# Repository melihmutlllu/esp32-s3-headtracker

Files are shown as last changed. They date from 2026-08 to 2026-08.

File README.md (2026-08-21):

# ESP32-S3 Wireless Head Tracker

Low-power WiFi head tracker firmware for ESP32-S3 Mini + MPU9xxx-style IMU modules, designed for OpenTrack and sim games such as Euro Truck Simulator 2 and Assetto Corsa.

The current tested sensor module behaves as a 6-axis MPU6500-compatible board. The firmware can probe/use an AK8963 magnetometer when a real MPU9250-compatible module exposes it, but gyro-only yaw will still drift slowly without a working magnetometer or another absolute yaw reference.

## Features

- ESP32-S3 Mini firmware for Arduino IDE / Arduino CLI
- MPU IMU over I2C at 400 kHz
- 125 Hz sensor sampling
- 60 Hz OpenTrack UDP output
- Startup gyro calibration from current still position
- Runtime recenter and gyro recalibration commands over serial
- Low TX power WiFi mode for lower heat
- Diagnostic sketch for MPU9250 / AK8963 magnetometer probing
- PC-side UDP listener tools for debugging

## Hardware

Custom PCB: TP4056 handles LiPo charging, an MCP1825S-SOT223 LDO regulates
3.3 V for the ESP32-S3 Mini and the IMU, and a slide switch gates the battery
line. Altium source is in [`hardware/altium/`](hardware/altium/); notes on
the tested wiring, axis mapping and power budget are in
[`docs/HARDWARE.md`](docs/HARDWARE.md).

| Component | Role |
|---|---|
| ESP32-S3 Mini | MCU, WiFi, runs the firmware |
| MPU9250 / MPU6500-compatible IMU | Motion sensing over I2C |
| TP4056 module | LiPo charge controller (USB input) |
| MCP1825S-SOT223 | 3.3 V LDO for the ESP32 + IMU rail |
| 1S LiPo battery | Power source |
| Slide switch | Power on/off |

| Schematic | 3D view | Routed layout |
|---|---|---|
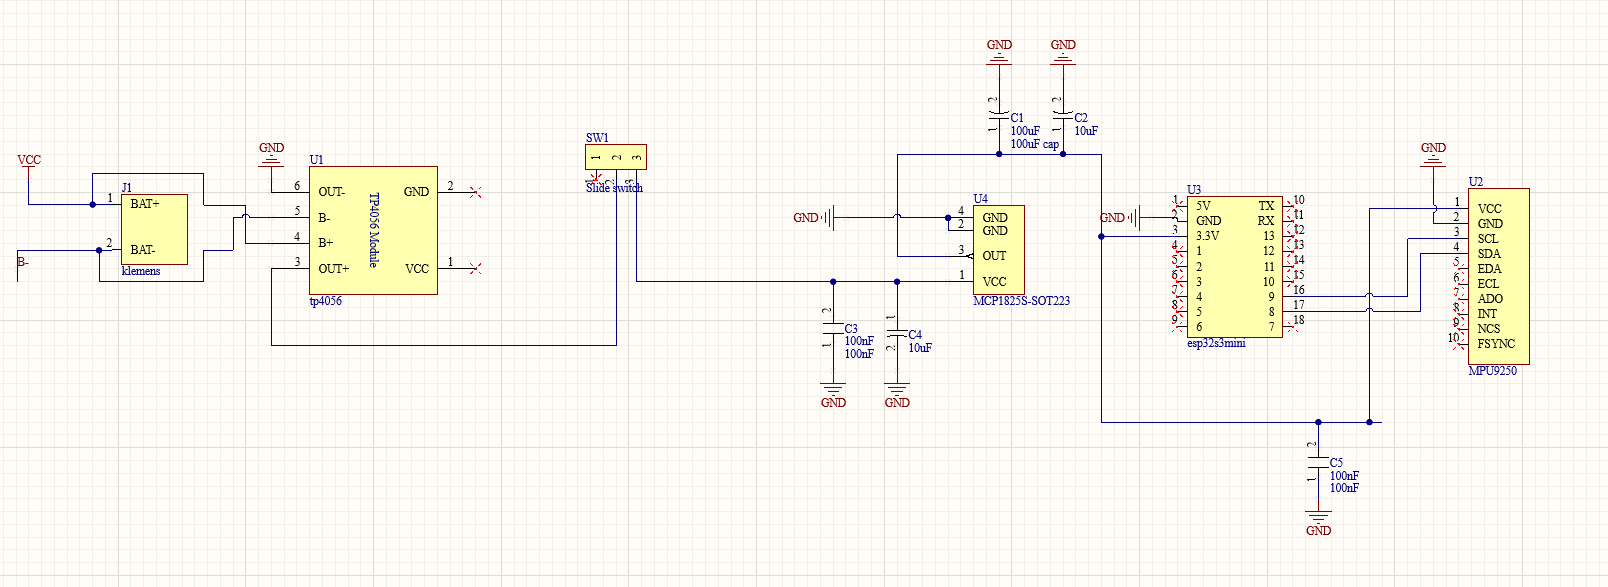
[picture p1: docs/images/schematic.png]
Schematic
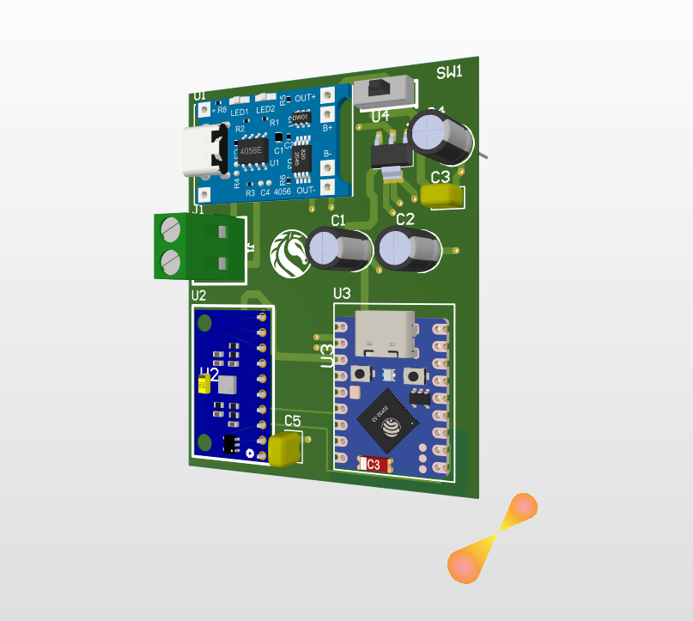
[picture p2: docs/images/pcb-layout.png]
Routed layout
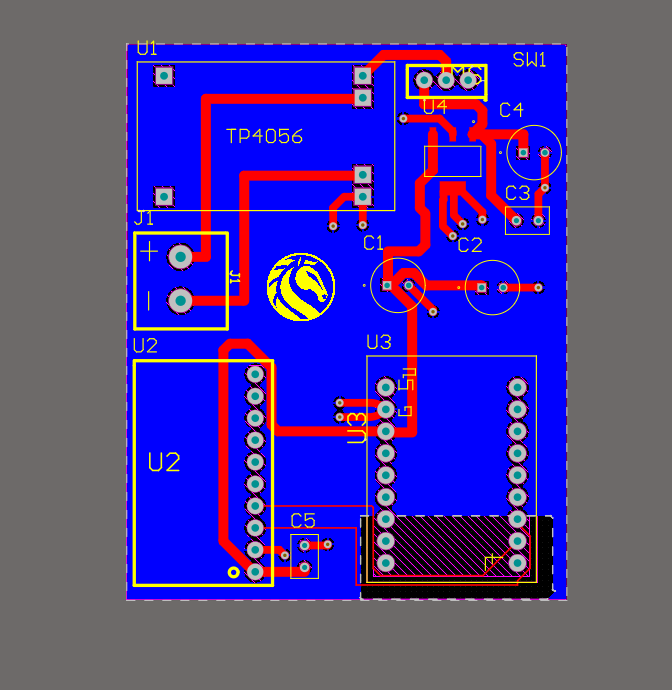
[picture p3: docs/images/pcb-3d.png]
3D view
|  |  |  |

## Repository Layout 

```text
firmware/headtracker_udp_lowpower/        Main firmware
firmware/diagnostics/mpu9250_deep_probe/ Deep MPU9250/AK8963 probe sketch
hardware/altium/                         Altium project (schematic, PCB, libraries)
tools/                                   PC-side debug tools
docs/                                    Setup, hardware and troubleshooting notes
```

## Quick Start

1. Open `firmware/headtracker_udp_lowpower/headtracker_udp_lowpower.ino` in Arduino IDE.
2. Copy `secrets.example.h` to `secrets.h` in the same folder.
3. Fill WiFi SSID, WiFi password, and the PC IPv4 address running OpenTrack.
4. Select the ESP32-S3 Mini board. The tested Arduino CLI FQBN is:

```powershell
esp32:esp32:lolin_s3_mini:CDCOnBoot=cdc
```

5. Upload the sketch.
6. Keep the tracker completely still during startup calibration.
7. In OpenTrack, use UDP input on port `4242`.

## Serial Commands

Send these from Arduino Serial Monitor:

```text
c  recenter current pose
b  recalibrate gyro bias and recenter; keep sensor still
m  toggle magnetometer yaw correction
s  scan I2C bus
h  print help
```

## OpenTrack Packet

The firmware sends one UDP packet containing six little-endian `double` values:

```text
tx, ty, tz, yaw_deg, pitch_deg, roll_deg
```

Only rotational axes are used. Roll is currently sent as `0` by default because the in-game setup was tuned with roll disabled.

## Important Notes

- Do not commit `secrets.h`; it contains WiFi credentials.
- If OpenTrack stops seeing the tracker after days/weeks, the PC IP probably changed. Update `HEADTRACKER_OPENTRACK_PC_IP` in `secrets.h`, or reserve a fixed DHCP address for the PC in the router.
- For real yaw drift correction, use a module with a working magnetometer or add an external magnetometer on the I2C bus.
- A real MPU9250/AK8963 setup should show `0x68` and `0x0C` in the I2C scan, with AK8963 `WHO_AM_I = 0x48`.

## Demo

Demo video (https://youtube.com/shorts/CIPEAHezTM8)

The tracker responding to head movement in real time, hand-held for clarity.
This clip is running on an earlier perfboard prototype rather than the PCB
shown above; the wiring is the same as the schematic.

## Status

PCB designed and firmware validated on the bench (prototype hardware); a
populated version of the board above and an enclosure are the next steps.

## License

MIT — see [LICENSE](LICENSE).

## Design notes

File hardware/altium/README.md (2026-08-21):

# Altium Files

Custom PCB source for the tracker board: TP4056 charge input, MCP1825S-SOT223
3.3 V LDO feeding the ESP32-S3 Mini and MPU9250, and a slide switch on the
battery line.

```text
headtracking_.PrjPcb   Project file
headtracking.SchDoc    Schematic
PCB1.PcbDoc             Board layout
Schlib1.SchLib          Custom schematic symbols (module footprints as blocks)
PcbLib2.PcbLib          Custom PCB footprints
```

Renders/exports of the current revision are in [`../images`](../images):
[schematic](../images/schematic.png), [3D view](../images/pcb-3d.png),
[routed layout](../images/pcb-layout.png).

Open `headtracking_.PrjPcb` in Altium Designer to edit. Commit these
source/design file types when present:

```text
*.PrjPcb
*.SchDoc
*.PcbDoc
*.SchLib
*.PcbLib
*.OutJob
*.BomDoc
```

Generated/local folders are excluded by `.gitignore` and should not be committed:

```text
History/
__Previews/
Project Outputs*/
```

Suggested release/export structure if you want to publish manufacturing files:

```text
hardware/outputs/gerber/
hardware/outputs/assembly/
hardware/outputs/bom/
hardware/outputs/pdf/
```

`hardware/outputs/` is ignored by default. For public releases, attach generated Gerber/NC drill/BOM/assembly files to a GitHub Release, or remove that ignore rule when you intentionally want them tracked.

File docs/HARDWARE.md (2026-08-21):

# Hardware Notes

## Tested Wiring

ESP32-S3 Mini to IMU:

```text
ESP32-S3 3V3  -> IMU VCC
ESP32-S3 GND  -> IMU GND
ESP32-S3 GPIO8 -> IMU SDA
ESP32-S3 GPIO9 -> IMU SCL
```

The firmware configures I2C at `400 kHz`.

## Sensor Orientation

The current firmware maps the mounted sensor frame like this:

```text
logical X = sensor Y
logical Y = sensor X
logical Z = -sensor Z
```

The output signs are currently tuned so that right yaw and up pitch increase in OpenTrack.

## Power

WiFi bursts can expose weak 3.3 V supplies. For stable behavior:

- Use a clean 3.3 V rail.
- Budget at least 500 mA for the ESP32 board.
- Add local decoupling near the ESP32/IMU.
- A practical starting point is 470 uF bulk plus 10 uF and 100 nF close to the board.

If the board heats excessively from USB, test with a stable external 3.3 V supply and keep WiFi TX power low.

## Magnetometer Reality Check

For a real MPU9250 with AK8963 magnetometer, the deep probe should find:

```text
i2c_device=0x68
i2c_device=0x0C
ak8963_ack=true
ak8963_wia=0x48
```

If only `0x68` appears after bypass, the module behaves like a 6-axis MPU6500-style board or has a disconnected/faulty magnetometer.

SDO/AD0 only changes the main MPU address between `0x68` and `0x69`; it does not make the AK8963 magnetometer appear.

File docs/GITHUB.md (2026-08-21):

# Publishing via the GitHub Website

This project is meant to be uploaded through github.com's web UI, not `git push`.
No local git setup is required.

## Before Uploading

**Do not upload `firmware/headtracker_udp_lowpower/secrets.h` if you created one.**
`.gitignore` only protects you when you use `git`; a browser upload has no such
filter, so it's on you to leave that file out manually. Only
`secrets.example.h` should go up.

## Steps

1. On GitHub, create a new repository (e.g. `esp32-s3-headtracker`). Leave
   "Add a README" / `.gitignore` / license unchecked — this project already
   has them.
2. Open the empty repo, click **Add file > Upload files**.
3. Drag the whole project folder in (GitHub preserves subfolder structure —
   `firmware/`, `hardware/`, `docs/`, `tools/` will show up as-is). If it
   only accepts loose files in your browser, upload folder by folder instead.
4. Double-check `secrets.h` isn't in the list of staged files before you commit.
5. Commit directly to `main`.

## Limits to Know

- 25 MiB per file via the web uploader, up to 100 files per upload batch.
  The largest file here is `hardware/altium/PCB1.PcbDoc` at ~3.8 MB, so
  everything fits in one pass.
- If GitHub ever flags a file as too large or the folder drag doesn't work
  in your browser, upload `hardware/altium/` separately from the rest.

## Altium Sources

Already included in `hardware/altium/`:

```text
headtracking_.PrjPcb   Project file
headtracking.SchDoc    Schematic
PCB1.PcbDoc             Board layout
Schlib1.SchLib          Custom schematic symbols
PcbLib2.PcbLib          Custom PCB footprints
```

If you regenerate these in Altium later and re-upload, skip committing its
generated/local output folders (`History/`, `__Previews/`, `Project Outputs*/`).

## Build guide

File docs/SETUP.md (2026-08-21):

# Setup

## Arduino

Tested with Arduino IDE and the ESP32 board package.

Board/FQBN:

```powershell
esp32:esp32:lolin_s3_mini:CDCOnBoot=cdc
```

Compile with Arduino CLI:

```powershell
arduino-cli compile --fqbn esp32:esp32:lolin_s3_mini:CDCOnBoot=cdc firmware/headtracker_udp_lowpower
```

Upload example:

```powershell
arduino-cli upload -p COM23 --fqbn esp32:esp32:lolin_s3_mini:CDCOnBoot=cdc firmware/headtracker_udp_lowpower
```

## Local Secrets

Create:

```text
firmware/headtracker_udp_lowpower/secrets.h
```

from:

```text
firmware/headtracker_udp_lowpower/secrets.example.h
```

Example:

```cpp
#pragma once

#define HEADTRACKER_WIFI_SSID "your-wifi-name"
#define HEADTRACKER_WIFI_PASSWORD "your-wifi-password"
#define HEADTRACKER_OPENTRACK_PC_IP 192, 168, 1, 3
```

To find the PC IP on Windows:

```powershell
Get-NetIPAddress -AddressFamily IPv4
```

Use the IPv4 address of the WiFi adapter that is on the same network as the ESP32.

## OpenTrack

- Input: UDP over network
- Port: `4242`
- Output: FreeTrack 2.0 Enhanced, or TrackIR if a game needs it
- Filter: Accela is a good starting point

OpenTrack centering does not update the ESP32's internal center. For quick use this is fine, but for a more polished build add a physical recenter button or send the serial `c` command to the ESP32.

## Startup Calibration

Keep the tracker still after power-up. The firmware waits for WiFi, lets the board settle, and then collects gyro/accel calibration samples.

If the first calibration was noisy, keep it still and send:

```text
b
```

from Serial Monitor.

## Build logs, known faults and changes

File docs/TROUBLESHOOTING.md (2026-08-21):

# Troubleshooting

## OpenTrack Does Not See Data

Check the firmware serial output:

```text
wifi_status=3
local_ip=...
udp_target=PC_IP:4242
```

Then verify:

- The PC IPv4 address in `secrets.h` matches the current Windows WiFi IP.
- OpenTrack input is set to UDP on port `4242`.
- Windows firewall allows OpenTrack or the UDP listener.
- The ESP32 and PC are on the same network.

PC IP can change with DHCP. The clean fix is a DHCP reservation in the router.

## Test UDP Without OpenTrack

Close OpenTrack first, because only one program should bind port `4242`.

Python:

```powershell
python tools/udp_pose_receiver.py
```

PowerShell:

```powershell
powershell -ExecutionPolicy Bypass -File tools/listen_udp_4242.ps1
```

## Yaw Drift

Gyro-only yaw has no absolute reference, so it will drift. The firmware reduces drift with startup calibration and slow stationary gyro bias updates, but a working magnetometer or another external reference is required for true yaw correction.

If drift gets worse as the board warms:

1. Power the tracker.
2. Keep it completely still through startup calibration.
3. Let it sit still for another 30-60 seconds.
4. Recenter in OpenTrack.

If needed, send serial command:

```text
b
```

after the board is warm and completely still.

## Magnetometer Not Found

Run:

```text
firmware/diagnostics/mpu9250_deep_probe/mpu9250_deep_probe.ino
```

Expected for a working MPU9250/AK8963:

```text
i2c_device=0x68
i2c_device=0x0C
ak8963_wia=0x48
```

If `0x0C` never appears, the magnetometer is not accessible.

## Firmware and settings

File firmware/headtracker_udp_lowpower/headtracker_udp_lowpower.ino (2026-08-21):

#include <Arduino.h>
#include <esp_system.h>
#include <esp_wifi.h>
#include <WiFi.h>
#include <WiFiUdp.h>
#include <Wire.h>

#if __has_include("secrets.h")
#include "secrets.h"
#endif

// ESP32-S3 Mini + MPU9250 head-tracker fusion test.
// Serial commands:
//   c = recenter current head pose
//   b = recalibrate gyro bias and recenter (keep still)
//   m = toggle magnetometer yaw correction
//   s = scan I2C bus
//   h = print help

static constexpr uint8_t SDA_PIN = 8;
static constexpr uint8_t SCL_PIN = 9;
static constexpr uint8_t MPU_ADDR = 0x68;

static constexpr uint32_t SERIAL_BAUD = 115200;
static constexpr uint32_t I2C_CLOCK_HZ = 400000;
static constexpr uint32_t SAMPLE_RATE_HZ = 125;
static constexpr uint32_t PRINT_RATE_HZ = 1;
static constexpr uint32_t UDP_SEND_RATE_HZ = 60;
static constexpr uint16_t CALIBRATION_SAMPLES = 750;
static constexpr uint32_t POST_WIFI_CALIBRATION_SETTLE_MS = 5000;
static constexpr uint32_t MAX_FILTER_DT_US = 10000;
static constexpr uint32_t ECO_CPU_MHZ = 80;
static constexpr bool SERIAL_PLOTTER_MODE = false;
static constexpr bool ENABLE_WIFI_UDP = true;
static constexpr bool ENABLE_AP_FALLBACK = false;
static constexpr bool SEND_ROLL_TO_OPENTRACK = false;
static constexpr bool ENABLE_OUTPUT_SMOOTHING = false;
static constexpr bool ENABLE_AUTO_GYRO_BIAS = true;
static constexpr bool WIFI_LOW_LATENCY_MODE = true;
static constexpr bool USE_UNICAST_TARGET = true;
static constexpr bool ENABLE_MAG_YAW_CORRECTION = true;
static constexpr uint32_t MPU_BASE_SAMPLE_RATE_HZ = 1000;
static constexpr uint8_t MPU_SAMPLE_RATE_DIVIDER =
  static_cast<uint8_t>((MPU_BASE_SAMPLE_RATE_HZ / SAMPLE_RATE_HZ) - 1);
static constexpr wifi_power_t WIFI_TX_POWER = WIFI_POWER_2dBm;

static_assert(MPU_BASE_SAMPLE_RATE_HZ % SAMPLE_RATE_HZ == 0,
              "SAMPLE_RATE_HZ must divide the MPU 1 kHz base rate");

#ifndef HEADTRACKER_WIFI_SSID
#define HEADTRACKER_WIFI_SSID ""
#endif

#ifndef HEADTRACKER_WIFI_PASSWORD
#define HEADTRACKER_WIFI_PASSWORD ""
#endif

#ifndef HEADTRACKER_OPENTRACK_PC_IP
#define HEADTRACKER_OPENTRACK_PC_IP 192, 168, 1, 3
#endif

#ifndef HEADTRACKER_AP_SSID
#define HEADTRACKER_AP_SSID "ESP32-HeadTracker"
#endif

#ifndef HEADTRACKER_AP_PASSWORD
#define HEADTRACKER_AP_PASSWORD "headtrack123"
#endif

// Fill secrets.h for normal WiFi station mode. Leave HEADTRACKER_WIFI_SSID
// empty to make the ESP32 create its own test access point instead.
static const char WIFI_SSID[] = HEADTRACKER_WIFI_SSID;
static const char WIFI_PASSWORD[] = HEADTRACKER_WIFI_PASSWORD;
static const char AP_SSID[] = HEADTRACKER_AP_SSID;
static const char AP_PASSWORD[] = HEADTRACKER_AP_PASSWORD;

static constexpr uint16_t OPENTRACK_UDP_PORT = 4242;
static constexpr uint32_t WIFI_CONNECT_TIMEOUT_MS = 30000;
static constexpr uint32_t WIFI_RECONNECT_INTERVAL_MS = 5000;
static constexpr uint8_t MAX_CONSECUTIVE_I2C_ERRORS = 8;
static constexpr uint16_t CALIBRATION_MIN_GOOD_SAMPLES = (CALIBRATION_SAMPLES * 9) / 10;
static constexpr uint8_t CALIBRATION_MAX_ATTEMPTS = 3;
static constexpr float CALIBRATION_ACCEL_MIN_G = 0.80f;
static constexpr float CALIBRATION_ACCEL_MAX_G = 1.20f;
static constexpr float CALIBRATION_MAX_ACCEL_STD_G = 0.05f;
static constexpr float CALIBRATION_MAX_GYRO_STD_DPS = 0.80f;
static constexpr float AUTO_BIAS_ACCEL_MIN_G = 0.90f;
static constexpr float AUTO_BIAS_ACCEL_MAX_G = 1.10f;
static constexpr float AUTO_BIAS_GYRO_XY_MAX_DPS = 0.35f;
static constexpr float AUTO_BIAS_GYRO_Z_MAX_DPS = 0.80f;
static constexpr float AUTO_BIAS_ALPHA_XY = 0.00015f;
static constexpr float AUTO_BIAS_ALPHA_Z = 0.00055f;
static constexpr uint16_t AUTO_BIAS_SETTLE_SAMPLES = static_cast<uint16_t>((SAMPLE_RATE_HZ * 3) / 2);
static constexpr float OUTPUT_SMOOTH_TAU_SLOW_S = 0.090f;
static constexpr float OUTPUT_SMOOTH_TAU_FAST_S = 0.018f;
static constexpr float OUTPUT_SMOOTH_SPEED_SLOW_DPS = 20.0f;
static constexpr float OUTPUT_SMOOTH_SPEED_FAST_DPS = 180.0f;
static constexpr float OUTPUT_MAX_RATE_DPS = 900.0f;
static constexpr float MAG_YAW_SIGN = 1.0f;
static constexpr float MAG_YAW_CORRECTION_GAIN = 0.25f;
static constexpr float MAG_YAW_MAX_CORRECTION_DPS = 2.0f;
static constexpr float MAG_YAW_FILTER_TAU_S = 0.70f;
static constexpr float MAG_FIELD_MIN_UT = 10.0f;
static constexpr float MAG_FIELD_MAX_UT = 90.0f;
static constexpr float MAG_MAX_TRUSTED_ERROR_DEG = 45.0f;
static constexpr float MAG_CORRECTION_MAX_GYRO_DPS = 160.0f;
static constexpr float MAG_BIAS_X_UT = 0.0f;
static constexpr float MAG_BIAS_Y_UT = 0.0f;
static constexpr float MAG_BIAS_Z_UT = 0.0f;
static constexpr float MAG_SCALE_X = 1.0f;
static constexpr float MAG_SCALE_Y = 1.0f;
static constexpr float MAG_SCALE_Z = 1.0f;
static IPAddress OPENTRACK_PC_IP(HEADTRACKER_OPENTRACK_PC_IP);

// MPU9250 full scale settings used below:
// accel +/-4 g => 8192 LSB/g, gyro +/-500 dps => 65.5 LSB/dps.
static constexpr float ACCEL_LSB_PER_G = 8192.0f;
static constexpr float GYRO_LSB_PER_DPS = 65.5f;
static constexpr float TEMP_LSB_PER_C = 333.87f;
static constexpr float TEMP_OFFSET_C = 21.0f;
static constexpr float DEG_TO_RAD_F = 0.01745329251994329577f;
static constexpr float RAD_TO_DEG_F = 57.295779513082320876f;

// Register map subset.
static constexpr uint8_t REG_SMPLRT_DIV = 0x19;
static constexpr uint8_t REG_CONFIG = 0x1A;
static constexpr uint8_t REG_GYRO_CONFIG = 0x1B;
static constexpr uint8_t REG_ACCEL_CONFIG = 0x1C;
static constexpr uint8_t REG_ACCEL_CONFIG2 = 0x1D;
static constexpr uint8_t REG_INT_PIN_CFG = 0x37;
static constexpr uint8_t REG_ACCEL_XOUT_H = 0x3B;
static constexpr uint8_t REG_USER_CTRL = 0x6A;
static constexpr uint8_t REG_PWR_MGMT_1 = 0x6B;
static constexpr uint8_t REG_PWR_MGMT_2 = 0x6C;
static constexpr uint8_t REG_WHO_AM_I = 0x75;

// AK8963 magnetometer inside MPU9250. It is reached through I2C bypass.
static constexpr uint8_t MAG_ADDR = 0x0C;
static constexpr uint8_t MAG_REG_WIA = 0x00;
static constexpr uint8_t MAG_REG_ST1 = 0x02;
static constexpr uint8_t MAG_REG_HXL = 0x03;
static constexpr uint8_t MAG_REG_ST2 = 0x09;
static constexpr uint8_t MAG_REG_CNTL1 = 0x0A;
static constexpr uint8_t MAG_REG_CNTL2 = 0x0B;
static constexpr uint8_t MAG_REG_ASAX = 0x10;
static constexpr uint8_t MAG_MODE_POWER_DOWN = 0x00;
static constexpr uint8_t MAG_MODE_FUSE_ROM = 0x0F;
static constexpr uint8_t MAG_MODE_CONT_100HZ_16BIT = 0x16;

// Map sensor axes into a right-handed head/game frame:
//   logical X = physical roll axis  = sensor Y
//   logical Y = physical pitch axis = sensor X
//   logical Z = physical yaw axis   = -sensor Z
// The signs can still be adjusted later if OpenTrack direction feels reversed.
enum AxisIndex : uint8_t { AXIS_X = 0, AXIS_Y = 1, AXIS_Z = 2 };
static constexpr AxisIndex MAP_OUT_X = AXIS_Y;
static constexpr AxisIndex MAP_OUT_Y = AXIS_X;
static constexpr AxisIndex MAP_OUT_Z = AXIS_Z;
static constexpr float SIGN_OUT_X = 1.0f;
static constexpr float SIGN_OUT_Y = 1.0f;
static constexpr float SIGN_OUT_Z = -1.0f;

static constexpr float OUTPUT_YAW_SIGN = -1.0f;
static constexpr float OUTPUT_PITCH_SIGN = -1.0f;
static constexpr float OUTPUT_ROLL_SIGN = 1.0f;

// Mahony 6DOF gain. Higher follows accelerometer faster; lower is smoother.
static constexpr float MAHONY_TWO_KP = 2.0f * 1.0f;
static constexpr float MAHONY_TWO_KI = 2.0f * 0.02f;

static_assert(sizeof(double) == 8, "OpenTrack UDP packet needs 64-bit doubles");

struct RawImu {
  int16_t ax;
  int16_t ay;
  int16_t az;
  int16_t temp;
  int16_t gx;
  int16_t gy;
  int16_t gz;
};

struct Vec3 {
  float x;
  float y;
  float z;
};

struct Quat {
  float w;
  float x;
  float y;
  float z;
};

struct EulerDeg {
  float yaw;
  float pitch;
  float roll;
};

struct CalibrationResult {
  bool stable;
  uint16_t good;
  Vec3 gyroMeanDps;
  Vec3 accelMeanG;
  float gyroStdDps;
  float accelMeanMagG;
  float accelStdG;
};

static Vec3 gyroBiasDps = {0.0f, 0.0f, 0.0f};
static Vec3 integralFeedback = {0.0f, 0.0f, 0.0f};
static Quat attitude = {1.0f, 0.0f, 0.0f, 0.0f};
static Quat centerAttitude = {1.0f, 0.0f, 0.0f, 0.0f};
static EulerDeg smoothedEuler = {0.0f, 0.0f, 0.0f};
static uint32_t i2cErrors = 0;
static uint32_t lateLoops = 0;
static uint32_t lastSampleUs = 0;
static uint32_t nextSampleUs = 0;
static WiFiUDP udp;
static IPAddress udpTargetIp(255, 255, 255, 255);
static bool udpReady = false;
static uint32_t udpPacketsOk = 0;
static uint32_t udpPacketsFail = 0;
static uint32_t wifiReconnects = 0;
static uint8_t consecutiveI2cErrors = 0;
static uint32_t autoBiasUpdates = 0;
static uint16_t stationarySamples = 0;
static int lastUdpResult = 0;
static bool outputFilterInitialized = false;
static bool magReady = false;
static bool magYawCorrectionEnabled = ENABLE_MAG_YAW_CORRECTION;
static bool magProbeAck = false;
static bool magYawReferenceValid = false;
static bool magYawFilterInitialized = false;
static uint8_t magFailStage = 0;
static uint8_t magWhoAmI = 0x00;
static Vec3 magAsaScale = {1.0f, 1.0f, 1.0f};
static float magCenterYawDeg = 0.0f;
static float magFilteredRelativeYawDeg = 0.0f;
static float magYawCorrectionOffsetDeg = 0.0f;
static float magLastFieldUt = 0.0f;
static float magLastYawErrorDeg = 0.0f;
static uint32_t magReadOk = 0;
static uint32_t magReadFail = 0;
static uint32_t magRejected = 0;

static void resetMagYawReference();

static bool writeReg(uint8_t reg, uint8_t value) {
  for (uint8_t attempt = 0; attempt < 3; ++attempt) {
    Wire.beginTransmission(MPU_ADDR);
    Wire.write(reg);
    Wire.write(value);
    if (Wire.endTransmission(true) == 0) {
      return true;
    }
    delay(2);
  }
  return false;
}

static bool readBytes(uint8_t reg, uint8_t *buffer, size_t length) {
  Wire.beginTransmission(MPU_ADDR);
  Wire.write(reg);
  if (Wire.endTransmission(false) != 0) {
    return false;
  }

  const size_t received = Wire.requestFrom(MPU_ADDR, static_cast<uint8_t>(length), static_cast<uint8_t>(true));
  if (received != length) {
    while (Wire.available()) {
      Wire.read();
    }
    return false;
  }

  for (size_t i = 0; i < length; ++i) {
    buffer[i] = static_cast<uint8_t>(Wire.read());
  }
  return true;
}

static bool readReg(uint8_t reg, uint8_t &value) {
  return readBytes(reg, &value, 1);
}

static bool i2cAddressResponds(uint8_t addr) {
  Wire.beginTransmission(addr);
  return Wire.endTransmission(true) == 0;
}

static void scanI2cBus() {
  if (SERIAL_PLOTTER_MODE) {
    return;
  }

  writeReg(REG_USER_CTRL, 0x00);
  delay(10);
  writeReg(REG_INT_PIN_CFG, 0x02);
  delay(10);

  Serial.println("# i2c_scan_start");
  for (uint8_t addr = 1; addr < 127; ++addr) {
    Wire.beginTransmission(addr);
    const uint8_t err = Wire.endTransmission(true);
    if (err == 0) {
      Serial.print("# i2c_device=0x");
      if (addr < 0x10) {
        Serial.print('0');
      }
      Serial.println(addr, HEX);
    }
  }
  Serial.println("# i2c_scan_done");
}

static bool magWriteReg(uint8_t reg, uint8_t value) {
  for (uint8_t attempt = 0; attempt < 3; ++attempt) {
    Wire.beginTransmission(MAG_ADDR);
    Wire.write(reg);
    Wire.write(value);
    if (Wire.endTransmission(true) == 0) {
      return true;
    }
    delay(2);
  }
  return false;
}

static bool magReadBytes(uint8_t reg, uint8_t *buffer, size_t length) {
  Wire.beginTransmission(MAG_ADDR);
  Wire.write(reg);
  if (Wire.endTransmission(false) != 0) {
    return false;
  }

  const size_t received = Wire.requestFrom(MAG_ADDR, static_cast<uint8_t>(length), static_cast<uint8_t>(true));
  if (received != length) {
    while (Wire.available()) {
      Wire.read();
    }
    return false;
  }

  for (size_t i = 0; i < length; ++i) {
    buffer[i] = static_cast<uint8_t>(Wire.read());
  }
  return true;
}

static bool magReadReg(uint8_t reg, uint8_t &value) {
  return magReadBytes(reg, &value, 1);
}

static int16_t makeI16(uint8_t high, uint8_t low) {
  return static_cast<int16_t>((static_cast<uint16_t>(high) << 8) | low);
}

static bool readRawImu(RawImu &raw) {
  uint8_t b[14];
  if (!readBytes(REG_ACCEL_XOUT_H, b, sizeof(b))) {
    ++i2cErrors;
    return false;
  }

  raw.ax = makeI16(b[0], b[1]);
  raw.ay = makeI16(b[2], b[3]);
  raw.az = makeI16(b[4], b[5]);
  raw.temp = makeI16(b[6], b[7]);
  raw.gx = makeI16(b[8], b[9]);
  raw.gy = makeI16(b[10], b[11]);
  raw.gz = makeI16(b[12], b[13]);
  return true;
}

static Vec3 mapAxes(const Vec3 &v) {
  const float in[3] = {v.x, v.y, v.z};
  return {
    SIGN_OUT_X * in[MAP_OUT_X],
    SIGN_OUT_Y * in[MAP_OUT_Y],
    SIGN_OUT_Z * in[MAP_OUT_Z],
  };
}

static Vec3 accelGFromRaw(const RawImu &raw) {
  const Vec3 v = {
    static_cast<float>(raw.ax) / ACCEL_LSB_PER_G,
    static_cast<float>(raw.ay) / ACCEL_LSB_PER_G,
    static_cast<float>(raw.az) / ACCEL_LSB_PER_G,
  };
  return mapAxes(v);
}

static Vec3 gyroDpsFromRaw(const RawImu &raw) {
  const Vec3 v = {
    static_cast<float>(raw.gx) / GYRO_LSB_PER_DPS,
    static_cast<float>(raw.gy) / GYRO_LSB_PER_DPS,
    static_cast<float>(raw.gz) / GYRO_LSB_PER_DPS,
  };
  return mapAxes(v);
}

static bool configureMag() {
  magFailStage = 0;
  magProbeAck = false;

  if (!ENABLE_MAG_YAW_CORRECTION) {
    magReady = false;
    return true;
  }

  bool ok = true;
  ok &= writeReg(REG_USER_CTRL, 0x00);    // disable MPU internal I2C master
  delay(10);
  ok &= writeReg(REG_INT_PIN_CFG, 0x02);  // enable bypass to AK8963
  delay(10);

  magProbeAck = i2cAddressResponds(MAG_ADDR);
  if (!magProbeAck) {
    magWhoAmI = 0x00;
    magReady = false;
    magFailStage = 1;
    return false;
  }

  delay(10);
  if (!magWriteReg(MAG_REG_CNTL2, 0x01)) {  // soft reset
    magReady = false;
    magFailStage = 2;
    return false;
  }
  delay(100);
  if (!magWriteReg(MAG_REG_CNTL1, MAG_MODE_POWER_DOWN)) {
    magReady = false;
    magFailStage = 3;
    return false;
  }
  delay(10);

  if (!magReadReg(MAG_REG_WIA, magWhoAmI)) {
    magWhoAmI = 0x00;
    magReady = false;
    magFailStage = 4;
    return false;
  }

  if (magWhoAmI != 0x48) {
    magReady = false;
    magFailStage = 5;
    return false;
  }

  if (!magWriteReg(MAG_REG_CNTL1, MAG_MODE_FUSE_ROM)) {
    magReady = false;
    magFailStage = 6;
    return false;
  }
  delay(10);

  uint8_t asa[3] = {128, 128, 128};
  if (magReadBytes(MAG_REG_ASAX, asa, sizeof(asa))) {
    magAsaScale = {
      (static_cast<float>(asa[0]) - 128.0f) / 256.0f + 1.0f,
      (static_cast<float>(asa[1]) - 128.0f) / 256.0f + 1.0f,
      (static_cast<float>(asa[2]) - 128.0f) / 256.0f + 1.0f,
    };
  }

  if (!magWriteReg(MAG_REG_CNTL1, MAG_MODE_POWER_DOWN)) {
    magReady = false;
    magFailStage = 7;
    return false;
  }
  delay(10);
  if (!magWriteReg(MAG_REG_CNTL1, MAG_MODE_CONT_100HZ_16BIT)) {
    magReady = false;
    magFailStage = 8;
    return false;
  }
  delay(10);

  magReady = ok;
  magFailStage = ok ? 0 : 9;
  magYawReferenceValid = false;
  magYawFilterInitialized = false;
  return ok;
}

static bool readMagUt(Vec3 &magUt) {
  if (!magReady) {
    return false;
  }

  uint8_t st1 = 0x00;
  if (!magReadReg(MAG_REG_ST1, st1)) {
    ++magReadFail;
    return false;
  }

  if ((st1 & 0x01) == 0) {
    return false;
  }

  uint8_t b[7];
  if (!magReadBytes(MAG_REG_HXL, b, sizeof(b))) {
    ++magReadFail;
    return false;
  }

  if ((b[6] & 0x08) != 0) {
    ++magRejected;
    return false;
  }

  const int16_t rawX = makeI16(b[1], b[0]);
  const int16_t rawY = makeI16(b[3], b[2]);
  const int16_t rawZ = makeI16(b[5], b[4]);

  const Vec3 sensorUt = {
    static_cast<float>(rawX) * 0.15f * magAsaScale.x,
    static_cast<float>(rawY) * 0.15f * magAsaScale.y,
    static_cast<float>(rawZ) * 0.15f * magAsaScale.z,
  };

  Vec3 mapped = mapAxes(sensorUt);
  mapped.x = (mapped.x - MAG_BIAS_X_UT) * MAG_SCALE_X;
  mapped.y = (mapped.y - MAG_BIAS_Y_UT) * MAG_SCALE_Y;
  mapped.z = (mapped.z - MAG_BIAS_Z_UT) * MAG_SCALE_Z;

  const float field = sqrtf(mapped.x * mapped.x + mapped.y * mapped.y + mapped.z * mapped.z);
  magLastFieldUt = field;
  if (field < MAG_FIELD_MIN_UT || field > MAG_FIELD_MAX_UT) {
    ++magRejected;
    return false;
  }

  magUt = mapped;
  ++magReadOk;
  return true;
}

static float tempCFromRaw(const RawImu &raw) {
  return static_cast<float>(raw.temp) / TEMP_LSB_PER_C + TEMP_OFFSET_C;
}

static Vec3 vecAdd(const Vec3 &a, const Vec3 &b) {
  return {a.x + b.x, a.y + b.y, a.z + b.z};
}

static Vec3 vecSub(const Vec3 &a, const Vec3 &b) {
  return {a.x - b.x, a.y - b.y, a.z - b.z};
}

static Vec3 vecScale(const Vec3 &v, float s) {
  return {v.x * s, v.y * s, v.z * s};
}

static float vecDot(const Vec3 &a, const Vec3 &b) {
  return a.x * b.x + a.y * b.y + a.z * b.z;
}

static Vec3 vecCross(const Vec3 &a, const Vec3 &b) {
  return {
    a.y * b.z - a.z * b.y,
    a.z * b.x - a.x * b.z,
    a.x * b.y - a.y * b.x,
  };
}

static float vecMagnitude(const Vec3 &v) {
  return sqrtf(v.x * v.x + v.y * v.y + v.z * v.z);
}

static float clampFloat(float value, float minValue, float maxValue) {
  if (value < minValue) {
    return minValue;
  }
  if (value > maxValue) {
    return maxValue;
  }
  return value;
}

static float wrapAngle180(float angleDeg) {
  while (angleDeg > 180.0f) {
    angleDeg -= 360.0f;
  }
  while (angleDeg < -180.0f) {
    angleDeg += 360.0f;
  }
  return angleDeg;
}

static float angleDeltaDeg(float fromDeg, float toDeg) {
  return wrapAngle180(toDeg - fromDeg);
}

static Vec3 vecNormalize(const Vec3 &v, const Vec3 &fallback) {
  const float mag = vecMagnitude(v);
  if (mag <= 1.0e-6f) {
    return fallback;
  }
  return vecScale(v, 1.0f / mag);
}

static Quat quatNormalize(Quat q) {
  const float mag = sqrtf(q.w * q.w + q.x * q.x + q.y * q.y + q.z * q.z);
  if (mag <= 1.0e-6f) {
    return {1.0f, 0.0f, 0.0f, 0.0f};
  }
  const float inv = 1.0f / mag;
  return {q.w * inv, q.x * inv, q.y * inv, q.z * inv};
}

static Quat quatConjugate(const Quat &q) {
  return {q.w, -q.x, -q.y, -q.z};
}

static Quat quatMultiply(const Quat &a, const Quat &b) {
  return {
    a.w * b.w - a.x * b.x - a.y * b.y - a.z * b.z,
    a.w * b.x + a.x * b.w + a.y * b.z - a.z * b.y,
    a.w * b.y - a.x * b.z + a.y * b.w + a.z * b.x,
    a.w * b.z + a.x * b.y - a.y * b.x + a.z * b.w,
  };
}
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
void loop() {
  handleSerialCommands();
  serviceWifiReconnect();

  const uint32_t now = micros();
  if (static_cast<int32_t>(now - nextSampleUs) < 0) {
    idleUntilNextSample(now);
    return;
  }

  const uint32_t samplePeriodUs = 1000000UL / SAMPLE_RATE_HZ;
  if (now - nextSampleUs > samplePeriodUs) {
    ++lateLoops;
    nextSampleUs = now;
  } else {
    nextSampleUs += samplePeriodUs;
  }

  RawImu raw;
  if (!readRawImu(raw)) {
    ++consecutiveI2cErrors;
    if (consecutiveI2cErrors >= MAX_CONSECUTIVE_I2C_ERRORS) {
      recoverMpu();
    }
    return;
  }
  consecutiveI2cErrors = 0;

  const uint32_t tUs = micros();
  const uint32_t rawDtUs = tUs - lastSampleUs;
  lastSampleUs = tUs;
  uint32_t dtUs = rawDtUs;
  if (dtUs == 0 || dtUs > MAX_FILTER_DT_US) {
    dtUs = samplePeriodUs;
    ++lateLoops;
  }
  const float dt = static_cast<float>(dtUs) * 1.0e-6f;

  const Vec3 accel = accelGFromRaw(raw);
  const Vec3 rawGyroDps = gyroDpsFromRaw(raw);
  Vec3 gyro = vecSub(rawGyroDps, gyroBiasDps);
  serviceAutoGyroBias(rawGyroDps, gyro, accel);
  gyro = vecSub(rawGyroDps, gyroBiasDps);

  updateMahony(
    gyro.x * DEG_TO_RAD_F,
    gyro.y * DEG_TO_RAD_F,
    gyro.z * DEG_TO_RAD_F,
    accel,
    dt);

  const Quat relative = quatMultiply(quatConjugate(centerAttitude), attitude);
  const EulerDeg rawEuler = eulerFromQuat(relative);
  const EulerDeg magCorrectedEuler = applyMagYawCorrection(rawEuler, accel, gyro, dt);
  const EulerDeg euler = filterOutputEuler(magCorrectedEuler, dt);

  static uint32_t lastUdpUs = 0;
  const uint32_t udpPeriodUs = 1000000UL / UDP_SEND_RATE_HZ;
  if (tUs - lastUdpUs >= udpPeriodUs) {
    lastUdpUs += udpPeriodUs;
    if (tUs - lastUdpUs >= udpPeriodUs) {
      lastUdpUs = tUs;
    }
    sendOpenTrackPose(euler);
  }

  static uint32_t lastPrintUs = 0;
  const uint32_t printPeriodUs = 1000000UL / PRINT_RATE_HZ;
  if (tUs - lastPrintUs >= printPeriodUs) {
    lastPrintUs = tUs;

    if (SERIAL_PLOTTER_MODE) {
      Serial.print("Yaw:");
      Serial.print(euler.yaw, 2);
      Serial.print('\t');
      Serial.print("Pitch:");
      Serial.print(euler.pitch, 2);
      Serial.print('\t');
      Serial.print("Roll:");
      Serial.println(euler.roll, 2);
      return;
    }

    Serial.print("YPR,");
    Serial.print(tUs);
    Serial.print(',');
    Serial.print(dtUs);
    Serial.print(',');
    Serial.print(euler.yaw, 3);
    Serial.print(',');
    Serial.print(euler.pitch, 3);
    Serial.print(',');
    Serial.print(euler.roll, 3);
    Serial.print(',');
    Serial.print(accel.x, 5);
    Serial.print(',');
    Serial.print(accel.y, 5);
    Serial.print(',');
    Serial.print(accel.z, 5);
    Serial.print(',');
    Serial.print(vecMagnitude(accel), 5);
    Serial.print(',');
    Serial.print(gyro.x, 4);
    Serial.print(',');
    Serial.print(gyro.y, 4);
    Serial.print(',');
    Serial.print(gyro.z, 4);
    Serial.print(',');
    Serial.print(tempCFromRaw(raw), 2);
    Serial.print(',');
    Serial.print(i2cErrors);
    Serial.print(',');
    Serial.print(lateLoops);
    Serial.print(',');
    Serial.print(udpPacketsOk);
    Serial.print(',');
    Serial.print(udpPacketsFail);
    Serial.print(',');
    Serial.print(lastUdpResult);
    Serial.print(',');
    Serial.print(WiFi.isConnected() ? WiFi.RSSI() : 0);
    Serial.print(',');
    Serial.print(wifiReconnects);
    Serial.print(',');
    Serial.print(consecutiveI2cErrors);
    Serial.print(',');
    Serial.print(autoBiasUpdates);
    Serial.print(',');
    Serial.print(stationarySamples);
    Serial.print(',');
    Serial.print(magReadOk);
    Serial.print(',');
    Serial.print(magReadFail);
    Serial.print(',');
    Serial.print(magRejected);
    Serial.print(',');
    Serial.print(magLastFieldUt, 2);
    Serial.print(',');
    Serial.print(magLastYawErrorDeg, 3);
    Serial.print(',');
    Serial.println(magYawCorrectionOffsetDeg, 3);
  }
}

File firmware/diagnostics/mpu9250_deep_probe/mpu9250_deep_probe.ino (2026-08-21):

#include <Arduino.h>
#include <Wire.h>

static constexpr uint8_t SDA_PIN = 8;
static constexpr uint8_t SCL_PIN = 9;
static constexpr uint32_t SERIAL_BAUD = 115200;

static constexpr uint8_t MPU_ADDR_0 = 0x68;
static constexpr uint8_t MPU_ADDR_1 = 0x69;

static constexpr uint8_t REG_SMPLRT_DIV = 0x19;
static constexpr uint8_t REG_CONFIG = 0x1A;
static constexpr uint8_t REG_INT_PIN_CFG = 0x37;
static constexpr uint8_t REG_I2C_MST_CTRL = 0x24;
static constexpr uint8_t REG_I2C_SLV0_ADDR = 0x25;
static constexpr uint8_t REG_I2C_SLV0_REG = 0x26;
static constexpr uint8_t REG_I2C_SLV0_CTRL = 0x27;
static constexpr uint8_t REG_EXT_SENS_DATA_00 = 0x49;
static constexpr uint8_t REG_USER_CTRL = 0x6A;
static constexpr uint8_t REG_PWR_MGMT_1 = 0x6B;
static constexpr uint8_t REG_PWR_MGMT_2 = 0x6C;
static constexpr uint8_t REG_WHO_AM_I = 0x75;

static constexpr uint8_t AK8963_ADDR = 0x0C;
static constexpr uint8_t AK8963_REG_WIA = 0x00;
static constexpr uint8_t AK8963_REG_CNTL1 = 0x0A;
static constexpr uint8_t AK8963_REG_CNTL2 = 0x0B;

static uint8_t mpuAddr = MPU_ADDR_0;

static bool addrAck(uint8_t addr) {
  Wire.beginTransmission(addr);
  return Wire.endTransmission(true) == 0;
}

static bool writeReg(uint8_t addr, uint8_t reg, uint8_t value) {
  Wire.beginTransmission(addr);
  Wire.write(reg);
  Wire.write(value);
  return Wire.endTransmission(true) == 0;
}

static bool readReg(uint8_t addr, uint8_t reg, uint8_t &value) {
  Wire.beginTransmission(addr);
  Wire.write(reg);
  if (Wire.endTransmission(false) != 0) {
    return false;
  }
  if (Wire.requestFrom(addr, static_cast<uint8_t>(1), static_cast<uint8_t>(true)) != 1) {
    while (Wire.available()) {
      Wire.read();
    }
    return false;
  }
  value = static_cast<uint8_t>(Wire.read());
  return true;
}

static void printHexByte(uint8_t value) {
  Serial.print("0x");
  if (value < 0x10) {
    Serial.print('0');
  }
  Serial.print(value, HEX);
}

static void scanBus(const char *label) {
  Serial.print("# scan_start=");
  Serial.println(label);
  uint8_t found = 0;
  for (uint8_t addr = 1; addr < 127; ++addr) {
    Wire.beginTransmission(addr);
    const uint8_t err = Wire.endTransmission(true);
    if (err == 0) {
      Serial.print("# i2c_device=");
      printHexByte(addr);
      Serial.println();
      ++found;
    }
  }
  Serial.print("# scan_found_count=");
  Serial.println(found);
  Serial.print("# scan_done=");
  Serial.println(label);
}

static void readWhoAmI(uint8_t addr) {
  uint8_t who = 0x00;
  Serial.print("# probe_addr=");
  printHexByte(addr);
  Serial.print(",ack=");
  Serial.println(addrAck(addr) ? "true" : "false");

  if (readReg(addr, REG_WHO_AM_I, who)) {
    Serial.print("# mpu_whoami_addr_");
    printHexByte(addr);
    Serial.print('=');
    printHexByte(who);
    Serial.println();
  } else {
    Serial.print("# mpu_whoami_addr_");
    printHexByte(addr);
    Serial.println("=read_failed");
  }
}

static bool wakeMpu() {
  bool ok = true;
  ok &= writeReg(mpuAddr, REG_PWR_MGMT_1, 0x80);
  delay(100);
  ok &= writeReg(mpuAddr, REG_PWR_MGMT_1, 0x01);
  delay(10);
  ok &= writeReg(mpuAddr, REG_PWR_MGMT_2, 0x00);
  delay(10);
  ok &= writeReg(mpuAddr, REG_CONFIG, 0x03);
  ok &= writeReg(mpuAddr, REG_SMPLRT_DIV, 0x07);
  return ok;
}

static void forceBypass() {
  writeReg(mpuAddr, REG_USER_CTRL, 0x00);
  delay(20);
  writeReg(mpuAddr, REG_INT_PIN_CFG, 0x02);
  delay(100);
}

static void directAk8963Probe() {
  Serial.println("# direct_ak8963_probe_start");

  const bool ack = addrAck(AK8963_ADDR);
  Serial.print("# ak8963_ack=");
  Serial.println(ack ? "true" : "false");

  uint8_t wia = 0x00;
  if (readReg(AK8963_ADDR, AK8963_REG_WIA, wia)) {
    Serial.print("# ak8963_wia=");
    printHexByte(wia);
    Serial.println();
  } else {
    Serial.println("# ak8963_wia=read_failed");
  }

  bool writeOk = true;
  writeOk &= writeReg(AK8963_ADDR, AK8963_REG_CNTL2, 0x01);
  delay(100);
  writeOk &= writeReg(AK8963_ADDR, AK8963_REG_CNTL1, 0x00);
  delay(10);
  writeOk &= writeReg(AK8963_ADDR, AK8963_REG_CNTL1, 0x16);
  delay(10);
  Serial.print("# ak8963_mode_write_ok=");
  Serial.println(writeOk ? "true" : "false");
  Serial.println("# direct_ak8963_probe_done");
}

static void internalMasterAk8963Probe() {
  Serial.println("# internal_master_ak8963_probe_start");

  writeReg(mpuAddr, REG_INT_PIN_CFG, 0x00);
  delay(10);
  writeReg(mpuAddr, REG_USER_CTRL, 0x20);       // I2C_MST_EN
  delay(10);
  writeReg(mpuAddr, REG_I2C_MST_CTRL, 0x0D);    // 400 kHz-ish master clock
  delay(10);
  writeReg(mpuAddr, REG_I2C_SLV0_ADDR, 0x80 | AK8963_ADDR);
  writeReg(mpuAddr, REG_I2C_SLV0_REG, AK8963_REG_WIA);
  writeReg(mpuAddr, REG_I2C_SLV0_CTRL, 0x81);   // enable, read 1 byte
  delay(100);

  uint8_t ext = 0x00;
  if (readReg(mpuAddr, REG_EXT_SENS_DATA_00, ext)) {
    Serial.print("# internal_master_ak8963_wia=");
    printHexByte(ext);
    Serial.println();
  } else {
    Serial.println("# internal_master_ak8963_wia=read_failed");
  }

  writeReg(mpuAddr, REG_USER_CTRL, 0x00);
  delay(10);
  writeReg(mpuAddr, REG_INT_PIN_CFG, 0x02);
  delay(10);
  Serial.println("# internal_master_ak8963_probe_done");
}

static void runProbe() {
  Serial.println();
  Serial.println("# mpu9250_deep_probe");
  Serial.print("# SDA_PIN=");
  Serial.println(SDA_PIN);
  Serial.print("# SCL_PIN=");
  Serial.println(SCL_PIN);

  Wire.setClock(100000);
  delay(50);
  scanBus("initial_100khz");
  readWhoAmI(MPU_ADDR_0);
  readWhoAmI(MPU_ADDR_1);

  if (addrAck(MPU_ADDR_0)) {
    mpuAddr = MPU_ADDR_0;
  } else if (addrAck(MPU_ADDR_1)) {
    mpuAddr = MPU_ADDR_1;
  } else {
    Serial.println("# no_mpu_at_0x68_or_0x69");
    return;
  }

  Serial.print("# selected_mpu_addr=");
  printHexByte(mpuAddr);
  Serial.println();
  Serial.print("# wake_mpu_ok=");
  Serial.println(wakeMpu() ? "true" : "false");

  forceBypass();
  scanBus("bypass_100khz");
  directAk8963Probe();
  internalMasterAk8963Probe();

  Wire.setClock(400000);
  delay(50);
  forceBypass();
  scanBus("bypass_400khz");
  directAk8963Probe();

  Serial.println("# deep_probe_done");
}

void setup() {
  Serial.begin(SERIAL_BAUD);
  const uint32_t startMs = millis();
  while (!Serial && millis() - startMs < 3000) {
    delay(10);
  }

  Wire.begin(SDA_PIN, SCL_PIN);
  delay(100);
  runProbe();
}

void loop() {
  static bool prompted = false;
  if (!prompted) {
    prompted = true;
    Serial.println("# send r to rerun deep probe");
  }

  while (Serial.available() > 0) {
    const char c = static_cast<char>(Serial.read());
    if (c == 'r' || c == 'R') {
      runProbe();
    }
  }
  delay(20);
}
